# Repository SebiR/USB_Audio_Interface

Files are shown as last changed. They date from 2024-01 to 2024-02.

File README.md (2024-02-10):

# USB Audio Interface with Line In or Out
A very compact USB sound card with either two line inputs or two line outputs

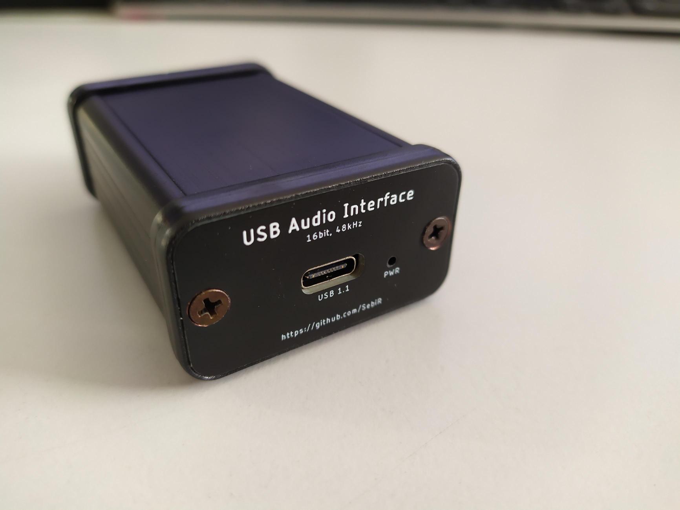
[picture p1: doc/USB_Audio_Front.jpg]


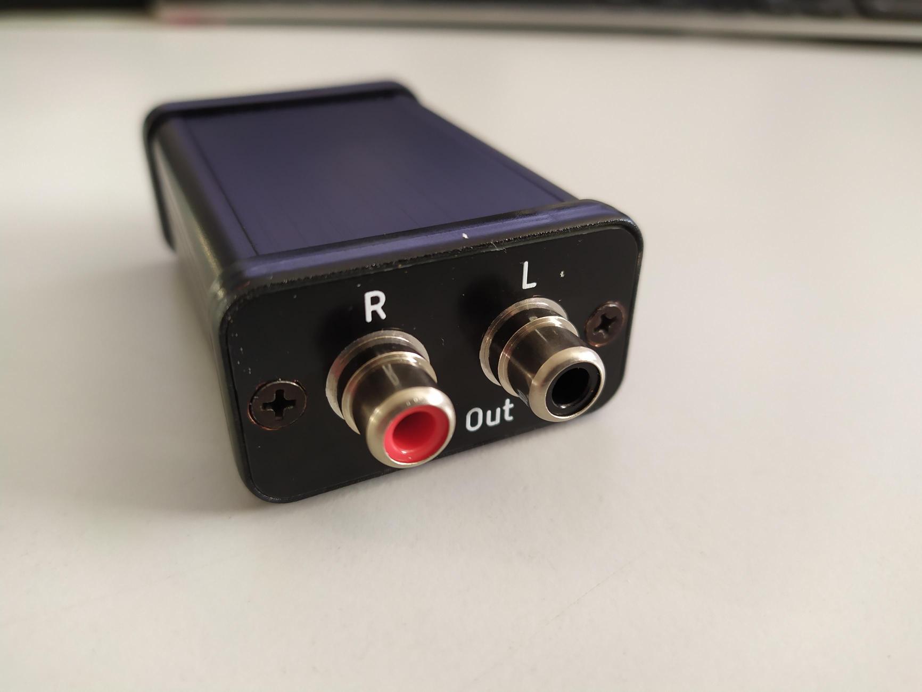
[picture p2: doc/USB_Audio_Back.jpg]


## Features
* USB-C connector (USB 1.1 standard)
* Can be set to Line Out or Line In with solder jumpers
* The front plate can be flipped for Input or Output labeling
* Bus powered
* With PCB front plates no mechanical work is neccessary (except for some countersinking)

# Inner Workings

The main chip of the audio interface is a PCM2904 from Texas Instruments. It has an in- and output capability of 16bit at 48kHz, enough for most applications.
A high-quality OPA2523 op amp is used as a low-pass filter to get rid of high frequency noise. It's basically a copy of the PCM2902 eval board from TI.

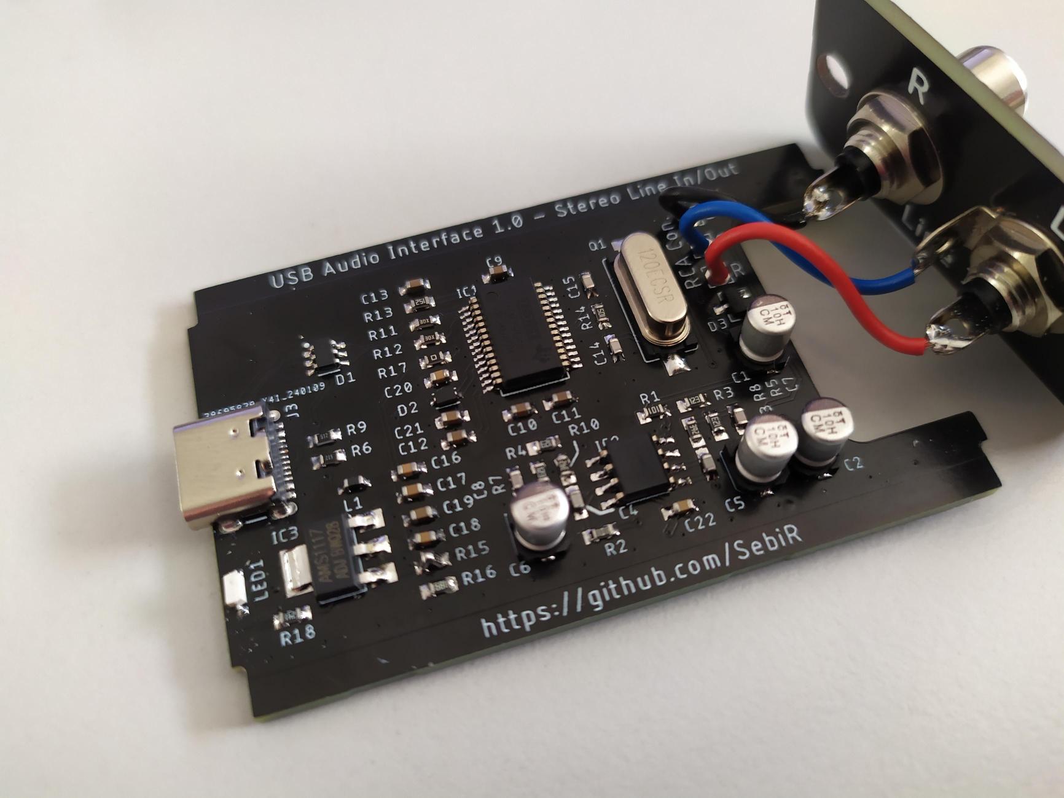
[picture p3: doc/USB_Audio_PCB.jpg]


On the underside, there are six SMT solder jumpers. Four of them determine the direction of the input/output LPF, so configuring the device as a Line In or a Line out device.
In case of a Line out configuration, the two inputs can be tied to GND to avoid any noise.

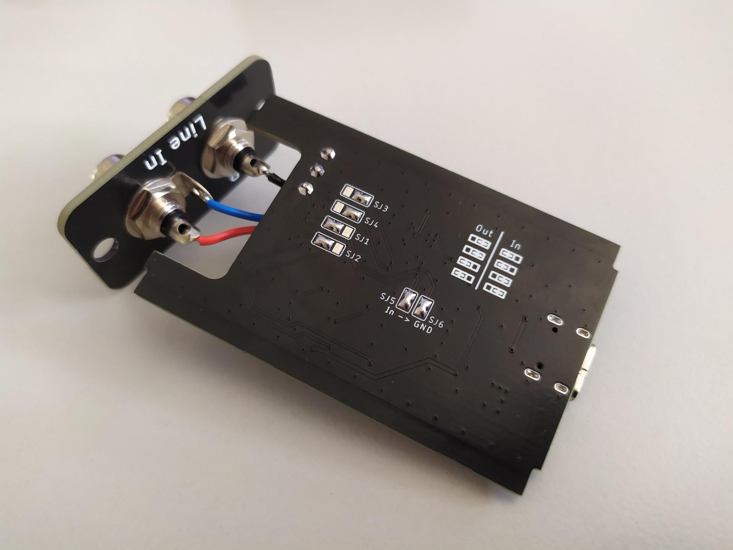
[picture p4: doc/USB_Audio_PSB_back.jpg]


# Case

The PCB and the front plates are designed to fit inside ultra small Hammond 1455D601 metal case.
But if you want to save ~15€, you can download the 3D CAD files for the case and print it for yourself:
https://www.hammfg.com/part/1455D601

Although a nice anodized aluminum case is pretty nifty!

# Maybe?
It would be really nice to be able to change the direction mid-operation, but that would require some analog switches. Maybe I'll create another version somewhere in the future

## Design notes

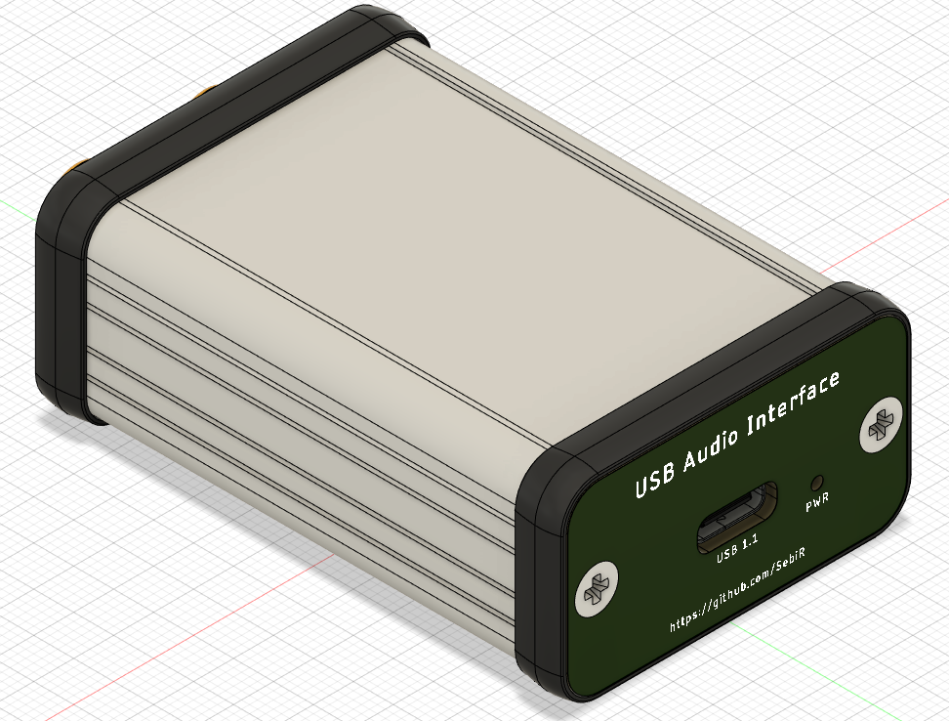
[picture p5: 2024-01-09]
doc/usb_side_render.png

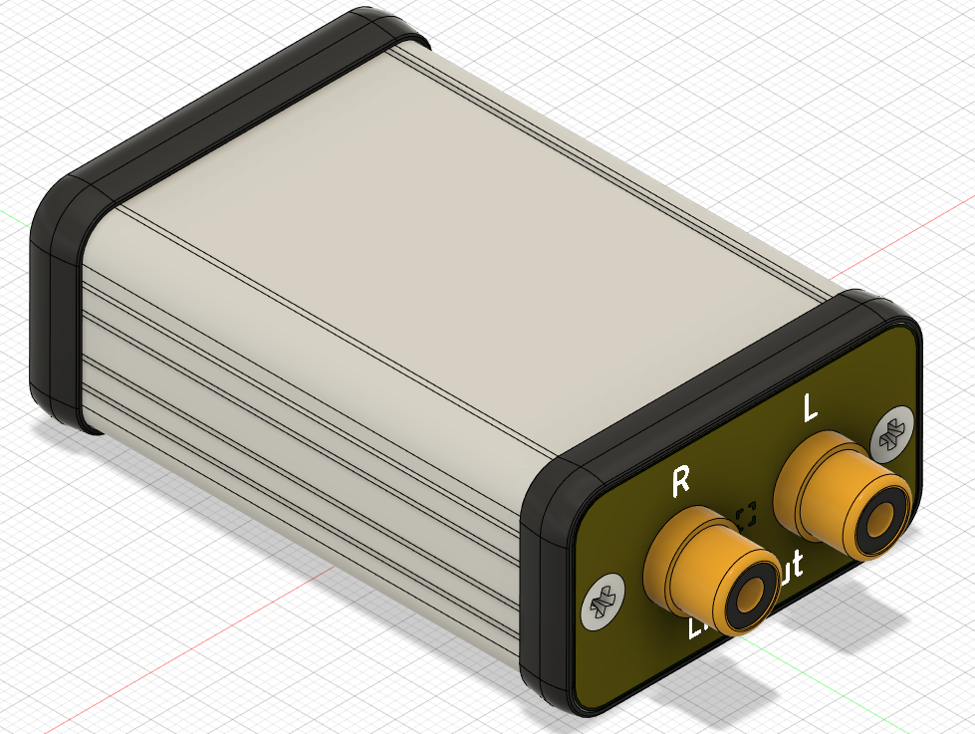
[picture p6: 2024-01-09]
doc/io_side_render.png

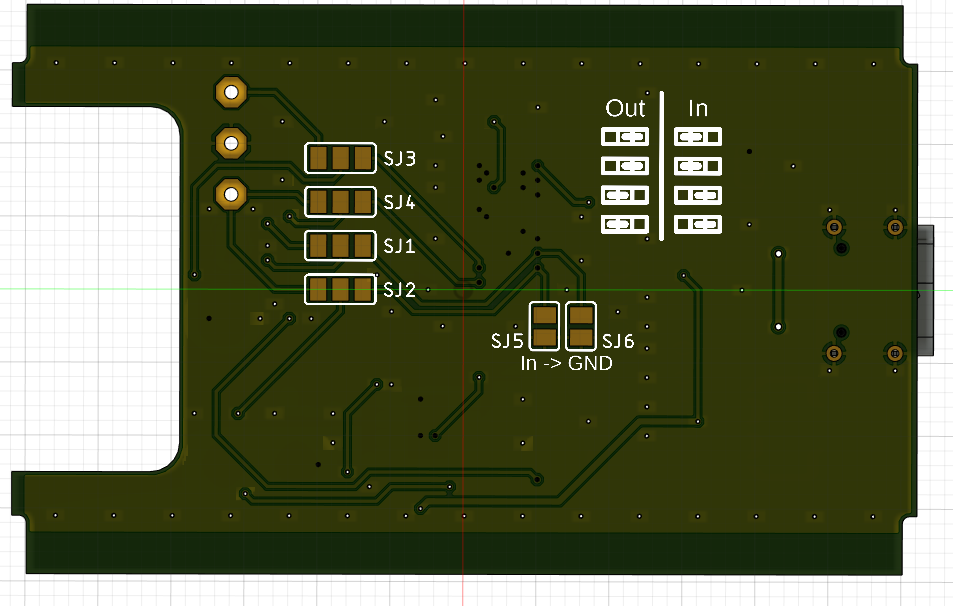
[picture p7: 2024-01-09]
doc/underside_render.png

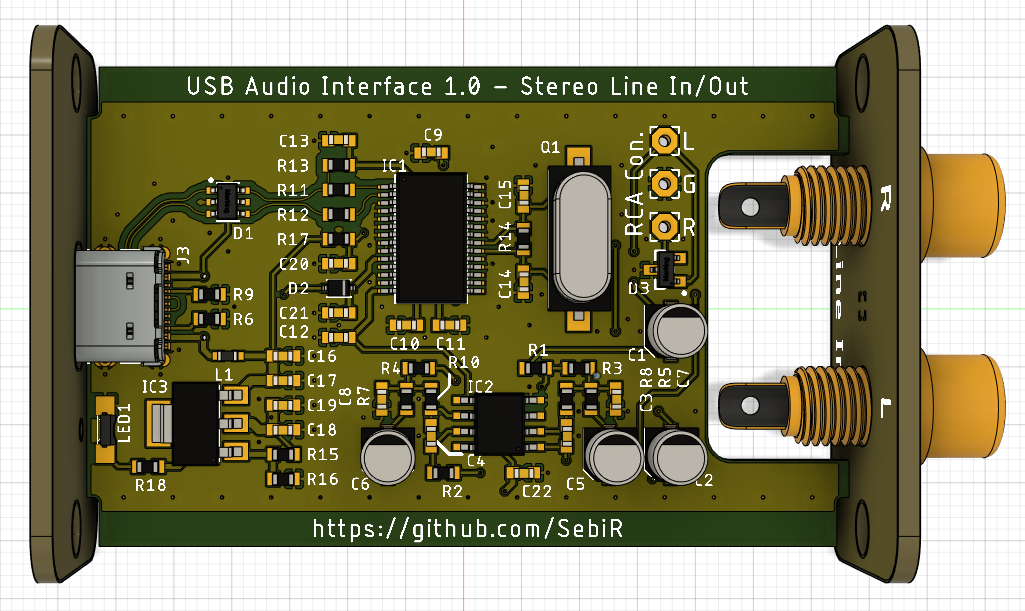
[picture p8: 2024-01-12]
doc/inside_render.png

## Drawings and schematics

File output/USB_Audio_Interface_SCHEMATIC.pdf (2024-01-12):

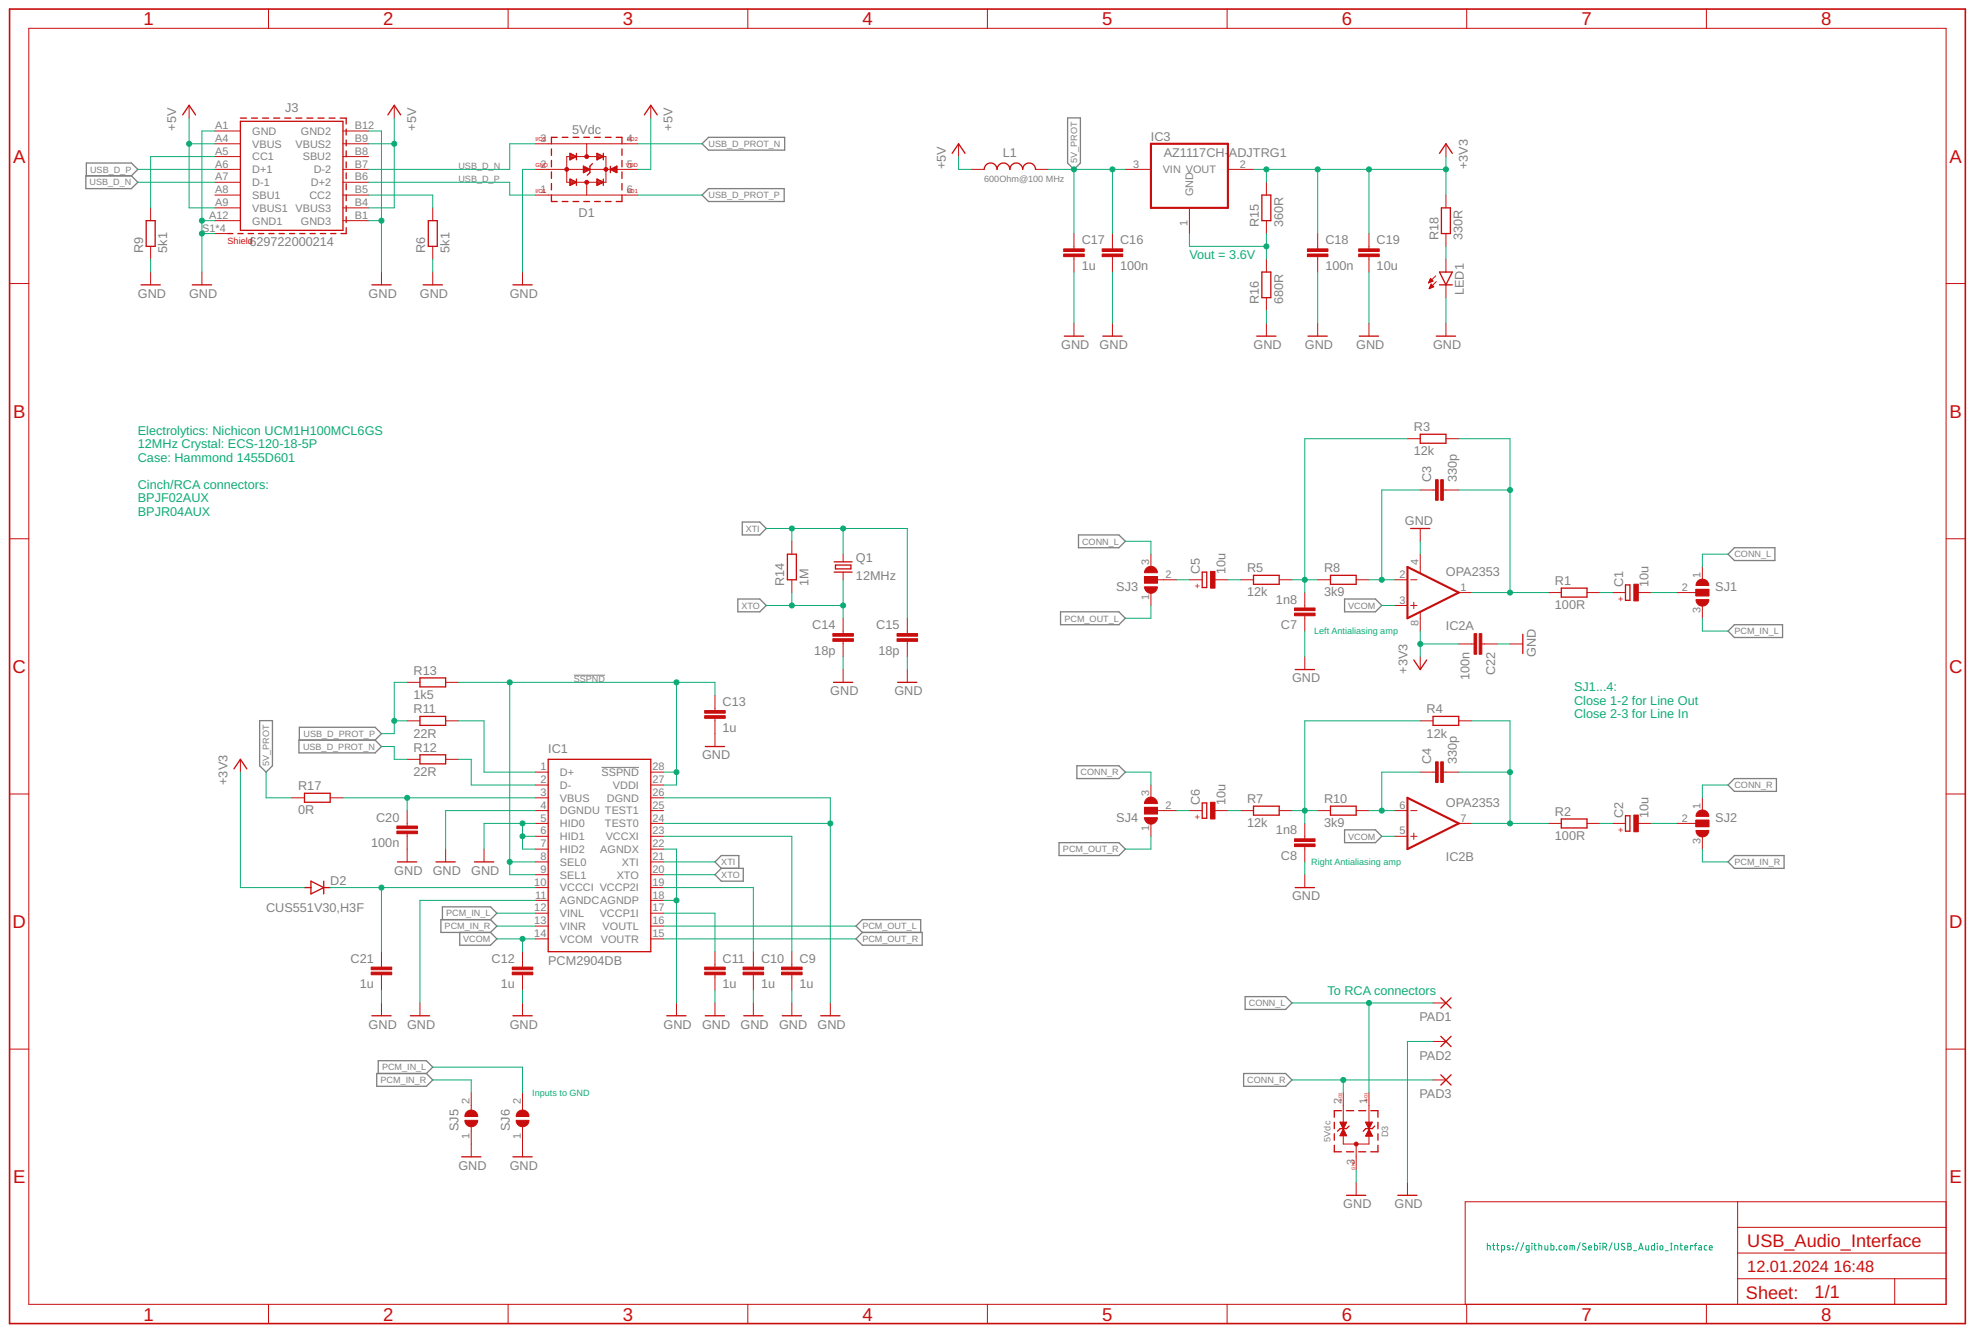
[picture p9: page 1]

SJ1...4: Close 1-2 for Line Out

Close 2-3 for Line In

1u GND GND GND GND

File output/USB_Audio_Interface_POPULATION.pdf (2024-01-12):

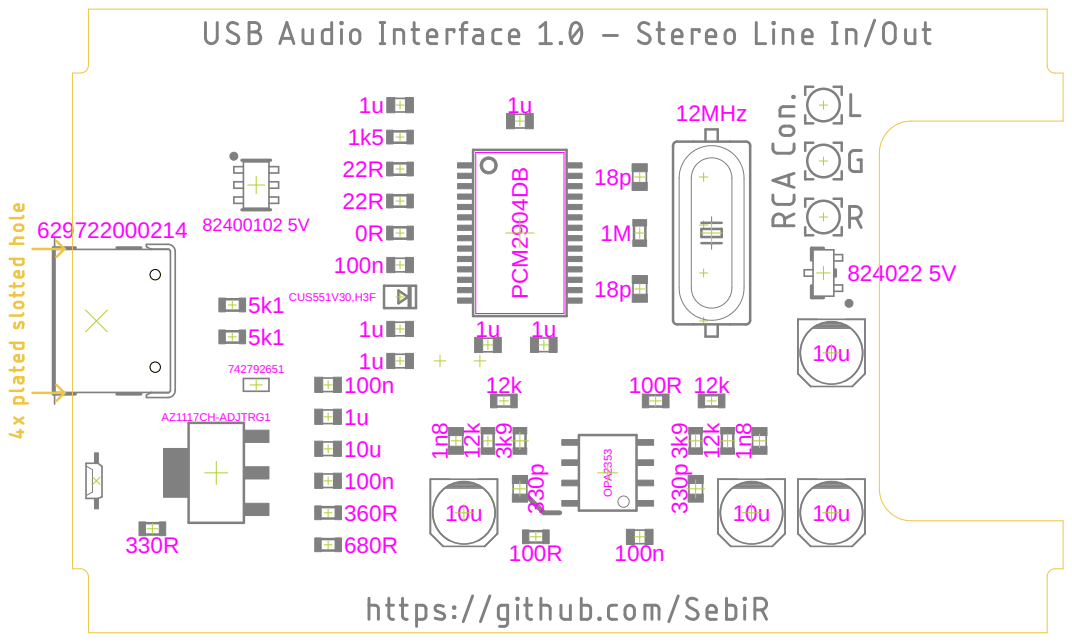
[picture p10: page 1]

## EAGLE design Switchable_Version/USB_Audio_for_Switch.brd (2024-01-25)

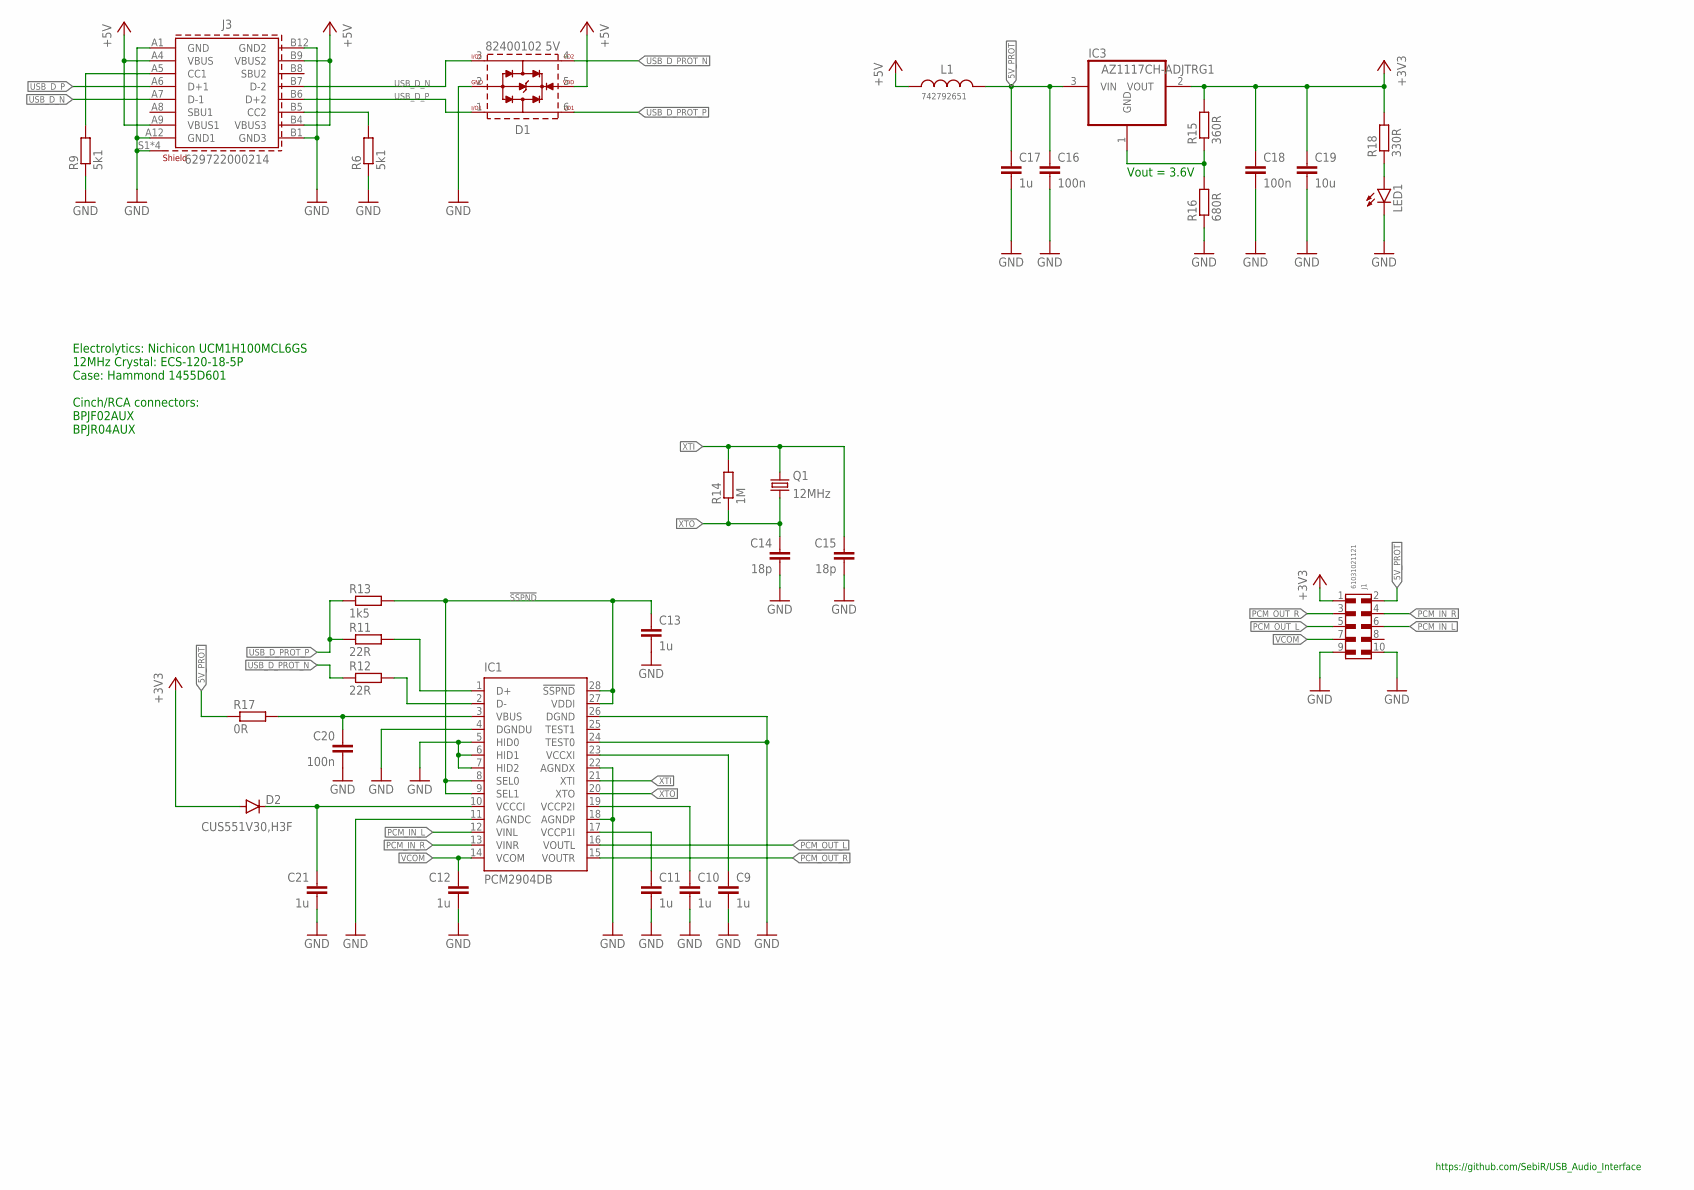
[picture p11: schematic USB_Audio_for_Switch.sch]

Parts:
C9, C10, C11, C12, C13, C17, C21: 1u; C0603
C14, C15: 18p; C0603
C16, C18, C20: 100n; C0603
C19: 10u; C0603
D1: 82400102 5V; WE-TVS_SOT23-6L
D2: CUS551V30,H3F; SOD323-R
IC1: PCM2904DB; SSOP28DB
IC3: AZ1117CH-ADJTRG1; SOT223
J1: 61031021121
J3: 629722000214
L1: 742792651; WE-CBF_0603_W2.6
LED1: LEDMICRO-SIDELED; MICRO-SIDELED
Q1: 12MHz; HC49UP
R6, R9: 5k1; R0603
R11, R12: 22R; R0603
R13: 1k5; R0603
R14: 1M; R0603
R15: 360R; R0603
R16: 680R; R0603
R17: 0R; R0603
R18: 330R; R0603

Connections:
5V_PROT: C16.1, C17.1, IC3.3 (VIN), J1.2, L1.2, R17.1
!SSPND: C13.1, IC1.8 (SEL0), IC1.9 (SEL1), IC1.27 (VDDI), IC1.28 (!SSPND), R13.2
+3V3: C18.1, C19.1, D2.A, IC3.2 (VOUT), J1.1, R15.2, R18.2
+5V: D1.5 (VDD), J3.A4 (VBUS), J3.A9 (VBUS1), J3.B4 (VBUS3), J3.B9 (VBUS2), L1.1
GND: C9.2, C10.2, C11.2, C12.2, C13.2, C14.2, C15.2, C16.2, C17.2, C18.2, C19.2, C20.2, C21.2, D1.2 (GND), IC1.4 (DGNDU), IC1.5 (HID0), IC1.6 (HID1), IC1.7 (HID2), IC1.11 (AGNDC), IC1.18 (AGNDP), IC1.22 (AGNDX), IC1.24 (TEST0), IC1.26 (DGND), J1.9, J1.10, J3.A1 (GND), J3.A12 (GND1), J3.B1 (GND3), J3.B12 (GND2), J3.S1 (SHIELD), J3.S2 (SHIELD), J3.S3 (SHIELD), J3.S4 (SHIELD), LED1.C, R6.1, R9.1, R16.1
unnamed: J3.A5 (CC1), R9.2
unnamed: J3.B5 (CC2), R6.2
unnamed: IC3.1 (GND), R15.1, R16.2
unnamed: LED1.A, R18.1
unnamed: C20.1, IC1.3 (VBUS), R17.2
unnamed: C9.1, IC1.23 (VCCXI)
unnamed: C11.1, IC1.17 (VCCP1I)
unnamed: C10.1, IC1.19 (VCCP2I)
unnamed: C21.1, D2.C, IC1.10 (VCCCI)
PCM_IN_L: IC1.12 (VINL), J1.6
PCM_IN_R: IC1.13 (VINR), J1.4
PCM_OUT_L: IC1.16 (VOUTL), J1.5
PCM_OUT_R: IC1.15 (VOUTR), J1.3
USB_D_N: D1.3 (I/O2), J3.A7 (D-1), J3.B7 (D-2)
USB_D_P: D1.1 (I/O1), J3.A6 (D+1), J3.B6 (D+2)
USB_D_PCM_N: IC1.2 (D-), R12.2
USB_D_PCM_P: IC1.1 (D+), R11.2
USB_D_PROT_N: D1.4 (I/O4), R12.1
USB_D_PROT_P: D1.6 (I/O3), R11.1, R13.1
VCOM: C12.1, IC1.14 (VCOM), J1.7
XTI: C15.1, IC1.21 (XTI), Q1.2, R14.2
XTO: C14.1, IC1.20 (XTO), Q1.1, R14.1

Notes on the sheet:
Electrolytics: Nichicon UCM1H100MCL6GS 12MHz Crystal: ECS-120-18-5P Case: Hammond 1455D601 Cinch/RCA connectors: BPJF02AUX BPJR04AUX
Vout = 3.6V
https://github.com/SebiR/USB_Audio_Interface

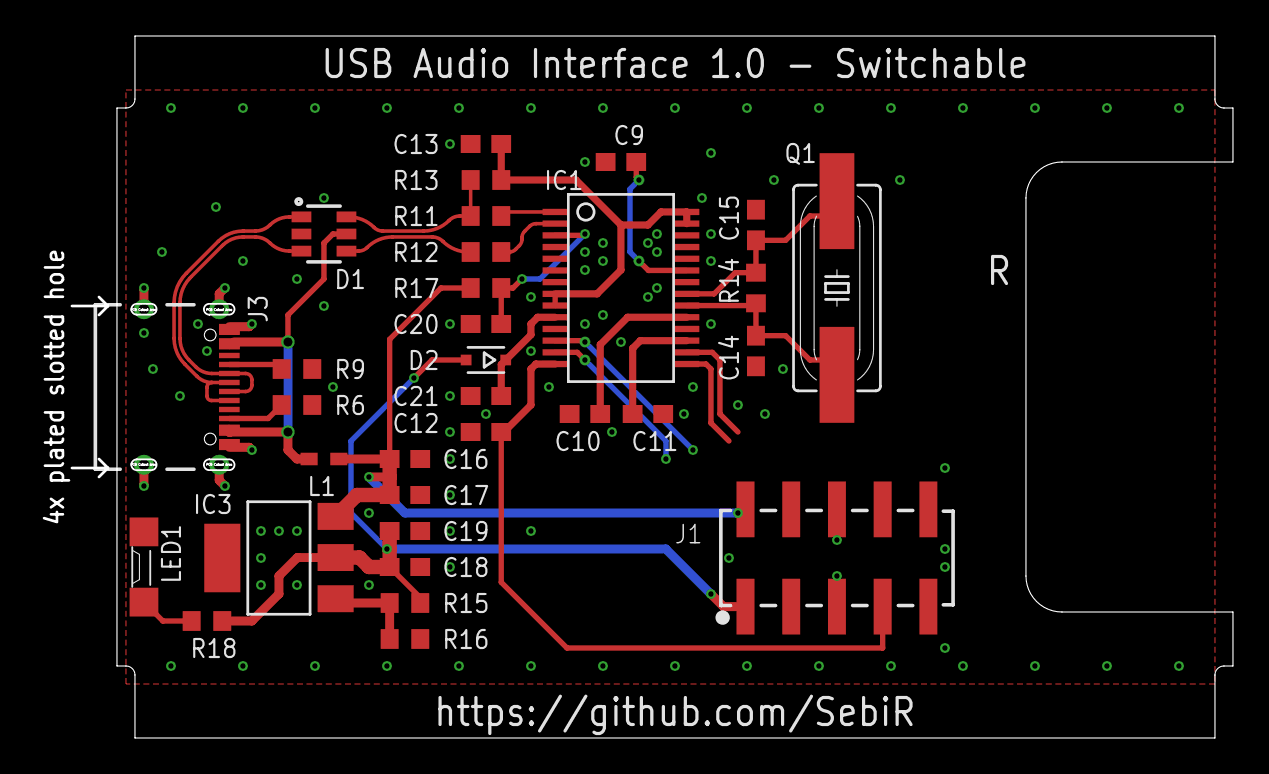
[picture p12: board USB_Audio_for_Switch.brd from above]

Board: 2 copper layers, 64.5 x 39.0 mm, 32 parts (0 on the bottom side), 27 nets.

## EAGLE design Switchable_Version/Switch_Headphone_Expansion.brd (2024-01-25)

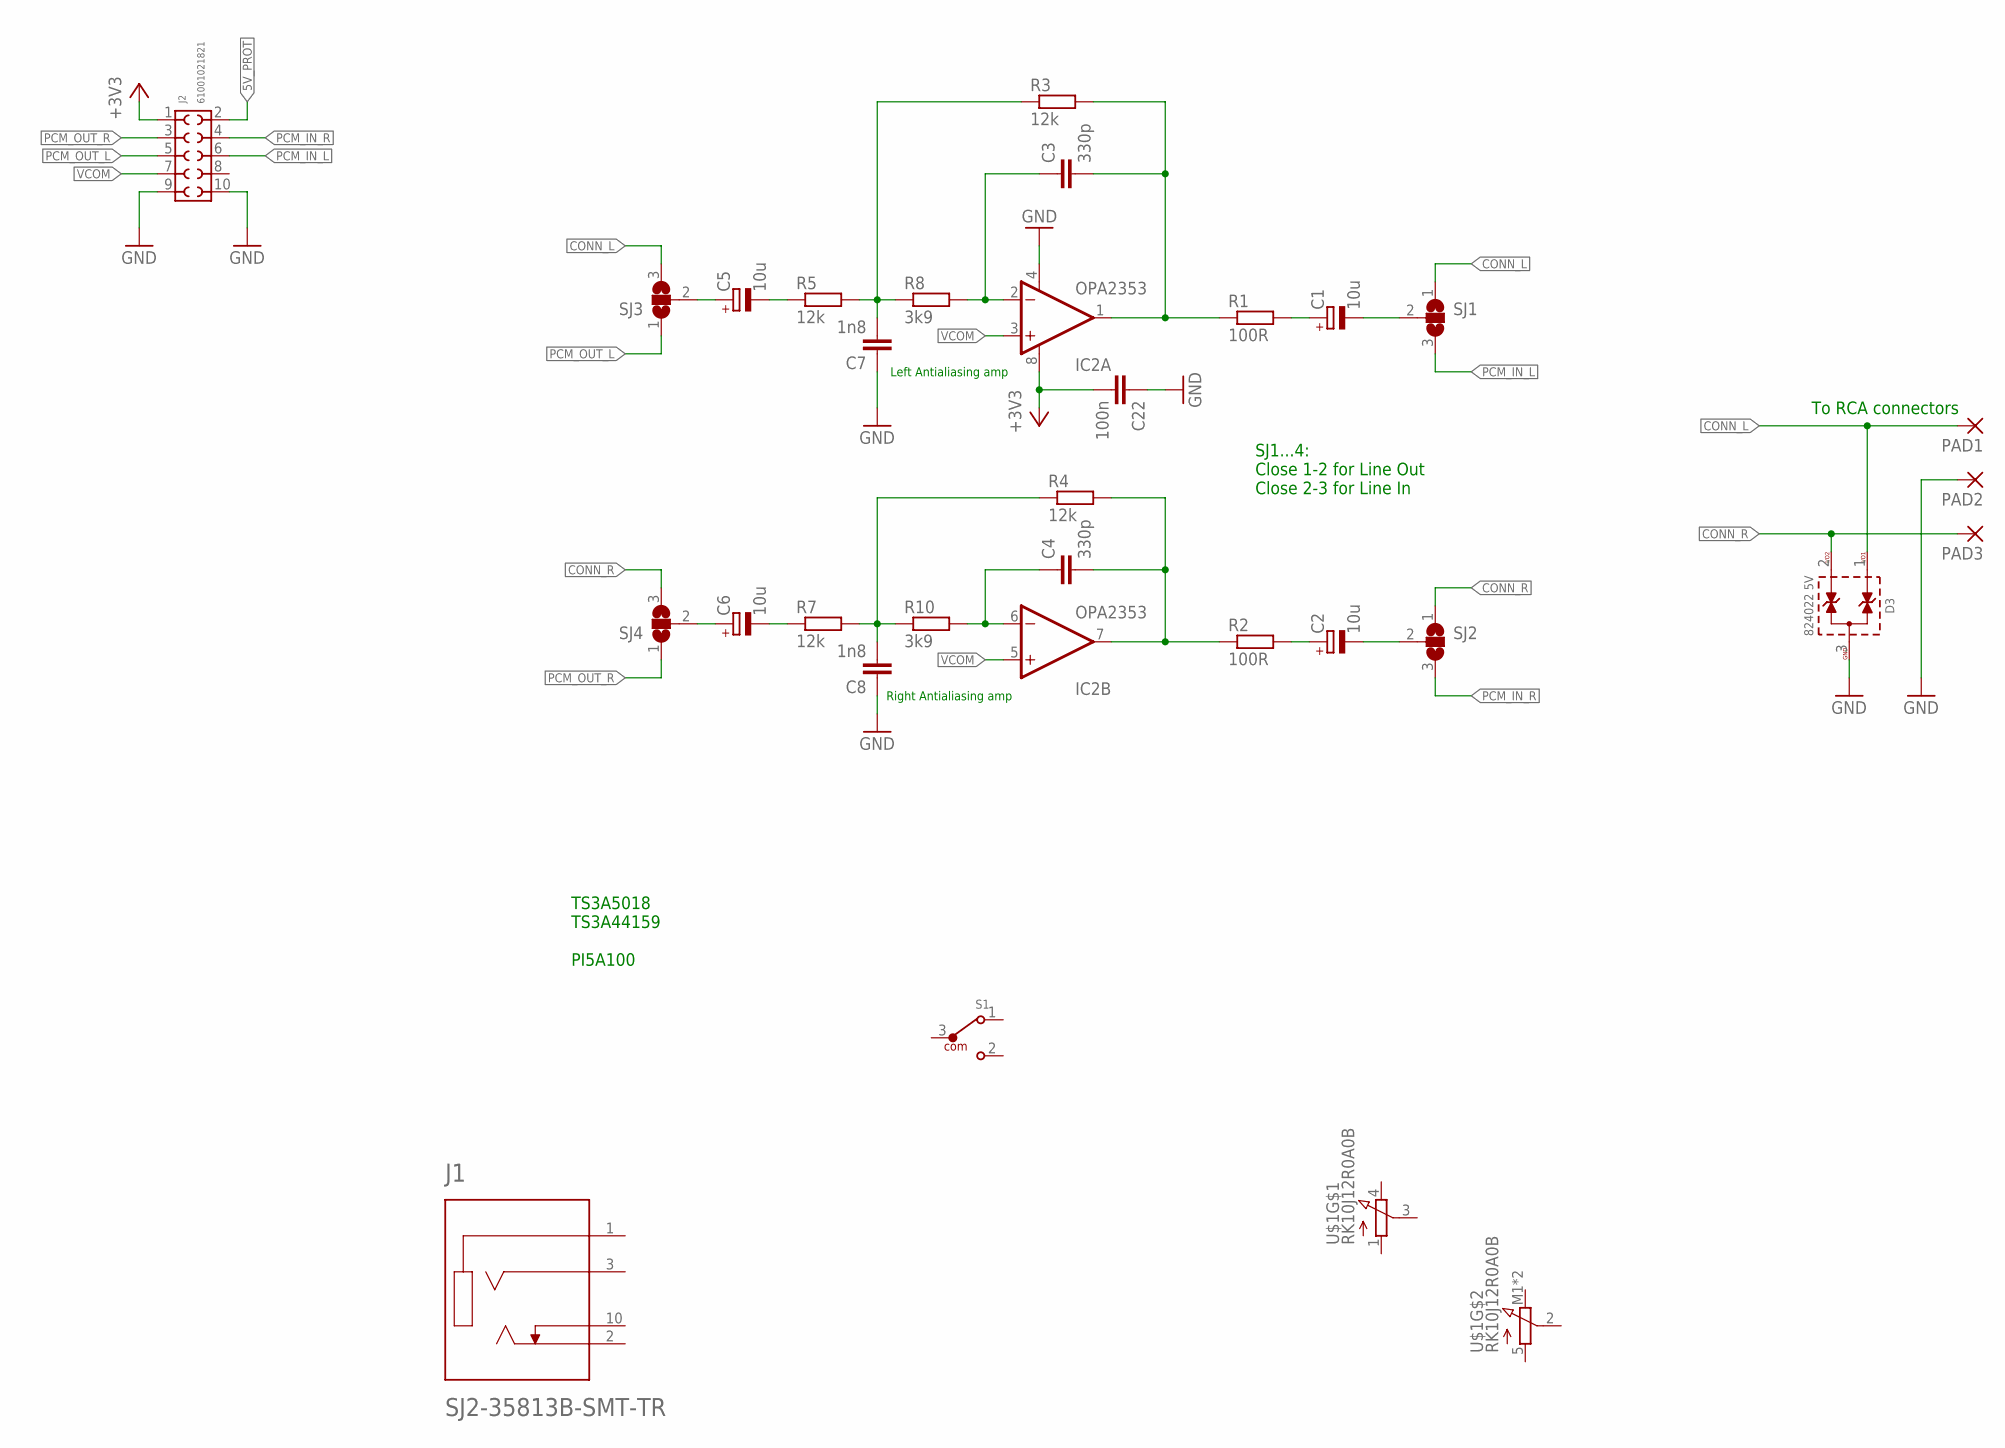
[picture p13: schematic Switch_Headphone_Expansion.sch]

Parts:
C1, C2, C5, C6: 10u; UD-4X5,8_NICHICON
C3, C4: 330p; C0603
C7, C8: 1n8; C0603
C22: 100n; C0603
D3: 824022 5V; WE-TVS_SOT23-3L
IC2: OPA2353; SO08
J1: SJ2-35813B-SMT-TR; CUI_SJ2-35813B-SMT-TR
J2: 61001021821
PAD1, PAD2, PAD3: 2,15/1,0
R1, R2: 100R; R0603
R3, R4, R5, R7: 12k; R0603
R8, R10: 3k9; R0603
S1: 450405020524
SJ1, SJ2, SJ3, SJ4: SJ2W; SJ_2
U$1: RK10J12R0A0B

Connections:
5V_PROT: J2.2
+3V3: C22.2, IC2.8 (V+), J2.1
CONN_L: D3.1 (I/O1), PAD1.1, SJ1.1, SJ3.3
CONN_R: D3.2 (I/O2), PAD3.1, SJ2.1, SJ4.3
GND: C7.1, C8.1, C22.1, D3.3 (GND), IC2.4 (V-), J2.9, PAD2.1
unnamed: C3.2, IC2.1 (OUT), R1.1, R3.2
unnamed: C4.2, IC2.7 (OUT), R2.1, R4.2
unnamed: C3.1, IC2.2 (-IN), R8.2
unnamed: C7.2, R3.1, R5.2, R8.1
unnamed: C5.-, R5.1
unnamed: C1.+, R1.2
unnamed: C2.+, R2.2
unnamed: C4.1, IC2.6 (-IN), R10.2
unnamed: C8.2, R4.1, R7.2, R10.1
unnamed: C6.-, R7.1
unnamed: C5.+, SJ3.2
unnamed: C6.+, SJ4.2
unnamed: C1.-, SJ1.2
unnamed: C2.-, SJ2.2
PCM_IN_L: J2.6, SJ1.3
PCM_IN_R: J2.4, SJ2.3
PCM_OUT_L: J2.5, SJ3.1
PCM_OUT_R: J2.3, SJ4.1
VCOM: IC2.3 (+IN), IC2.5 (+IN), J2.7

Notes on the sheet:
Right Antialiasing amp
Left Antialiasing amp
SJ1...4: Close 1-2 for Line Out Close 2-3 for Line In
TS3A5018 TS3A44159 PI5A100
To RCA connectors

Board: 2 copper layers, 30 parts (0 on the bottom side), 23 nets, no tracks yet.

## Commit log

2024-01-12 * Cleaned schematic a bit, exported new PDF * Cleaned up the PCB, USB has now its own netclass, updated GERBER * Updated image of PCB * Updated readme
    [USB_Audio_Interface.brd, USB_Audio_Interface.sch]
2024-01-12 * Fixed layout, two airwires on the USB removed
    [USB_Audio_Interface.brd]
2024-01-12 Updated tValue positions for easy population
    [USB_Audio_Interface.brd, USB_Audio_Interface.sch]
2024-01-12 Added population plan
    [USB_Audio_Interface.brd, USB_Audio_Interface.sch]
2024-01-25 Started on switchable version. Moved EAGLE files into individual folders
    [Switch_Headphone_Expansion.brd, Switch_Headphone_Expansion.sch, USB_Audio_Front_1.brd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]
2024-02-10 Added actual images of the PCBA

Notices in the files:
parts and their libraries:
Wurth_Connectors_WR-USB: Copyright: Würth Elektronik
